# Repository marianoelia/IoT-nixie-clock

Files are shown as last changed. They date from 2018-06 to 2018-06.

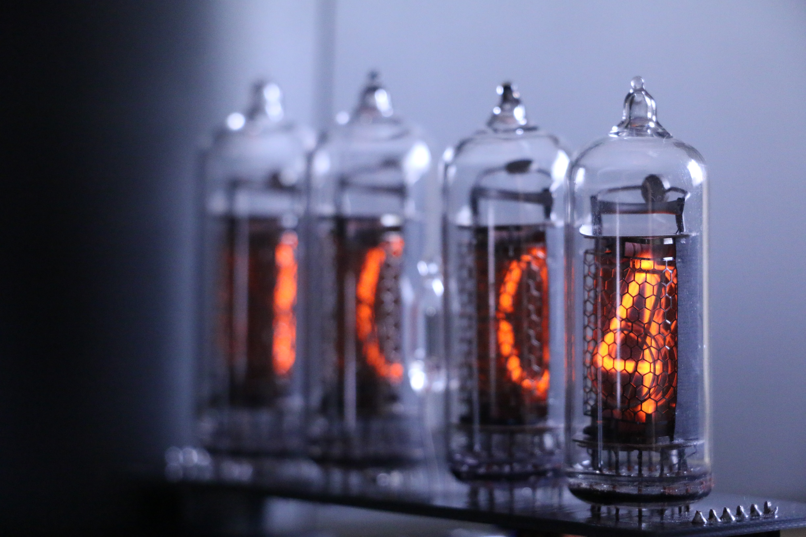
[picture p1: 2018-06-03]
Extra/Pictures/NixieClockColdLight.JPG

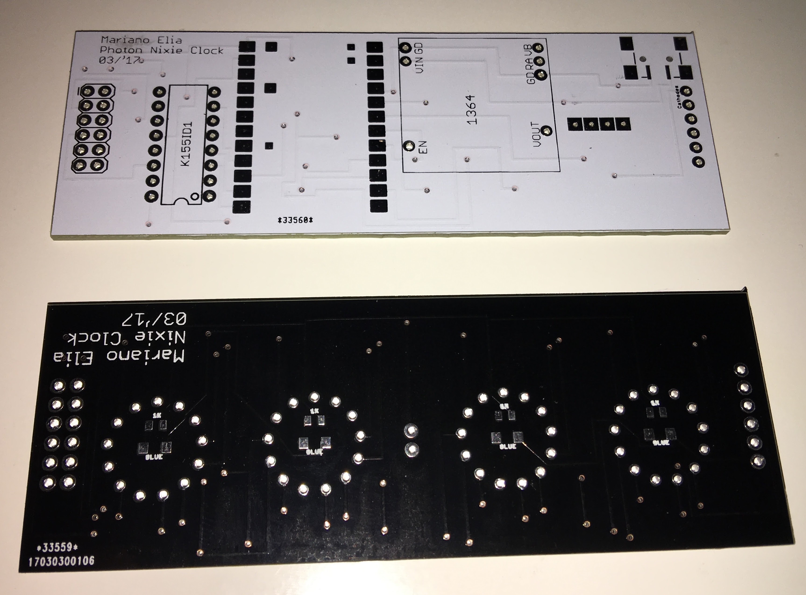
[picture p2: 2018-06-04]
Extra/Pictures/BoardsTopSide.JPG

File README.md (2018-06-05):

# Nixie Clock Project
[Link to hackster writeup tutorial](https://www.hackster.io/mrelia100/particle-photon-nixie-clock)

NixieClock

## Introduction
This is repo for my nixie clock build.

## License

This work is licensed under the  Creative Commons Attribution-ShareAlike 4.0 International License. To view a copy of this license, visit <http://creativecommons.org/licenses/by-sa/4.0/> or send a letter to Creative Commons, 444 Castro Street, Suite 900, Mountain View, California, 94041, USA.

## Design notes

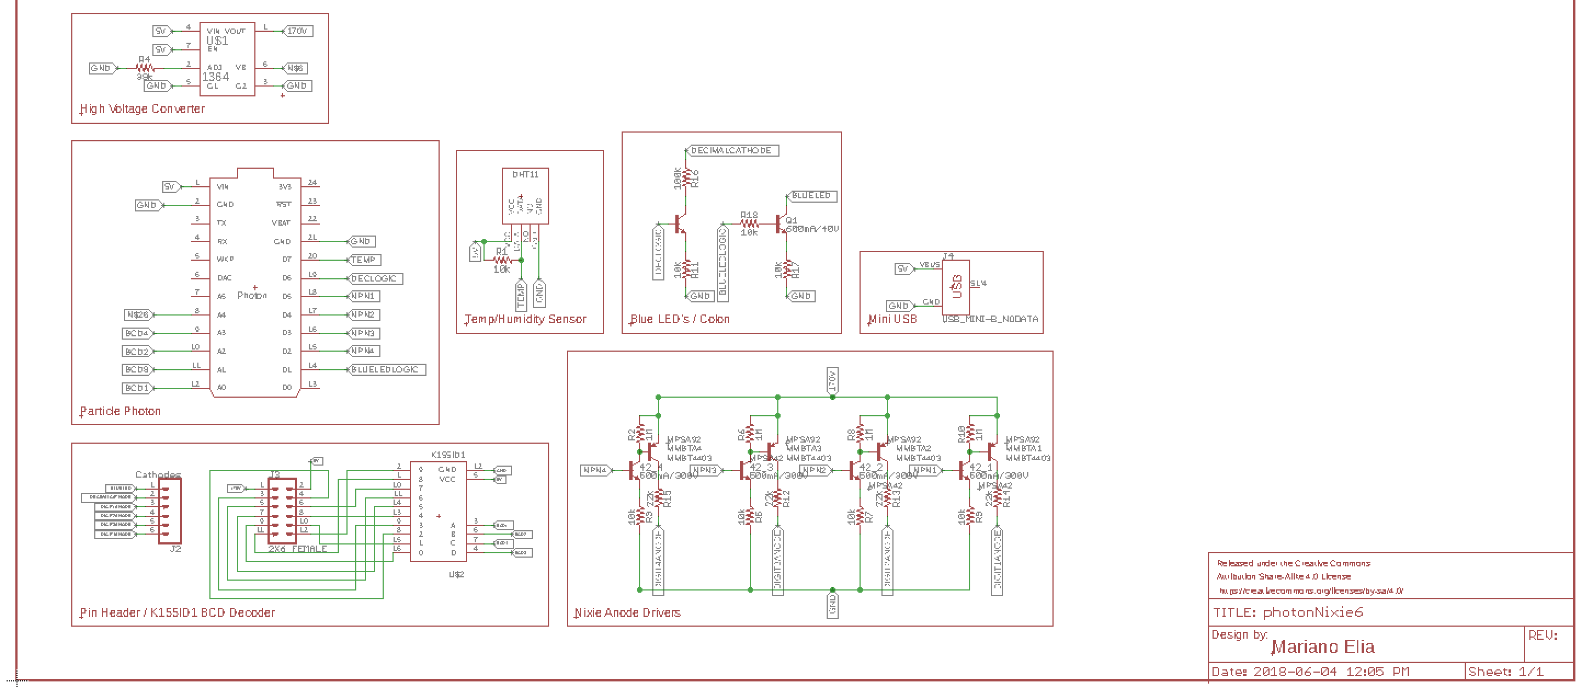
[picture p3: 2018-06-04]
BoardFiles/BottomBoard/Schematic.png

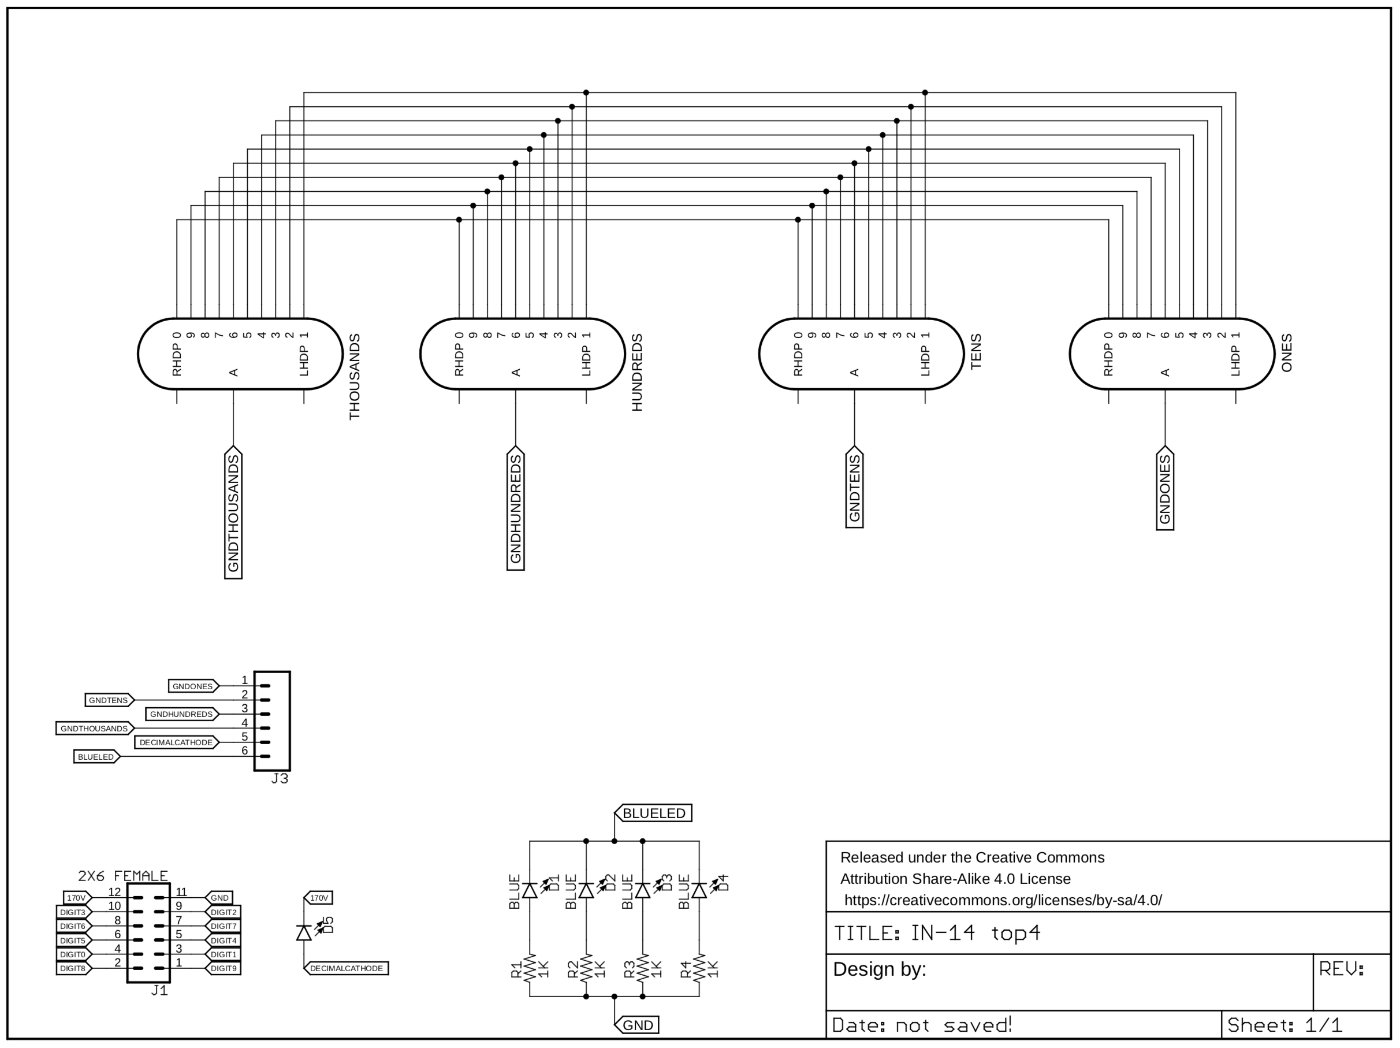
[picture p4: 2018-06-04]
BoardFiles/TopBoard/Schematic.png

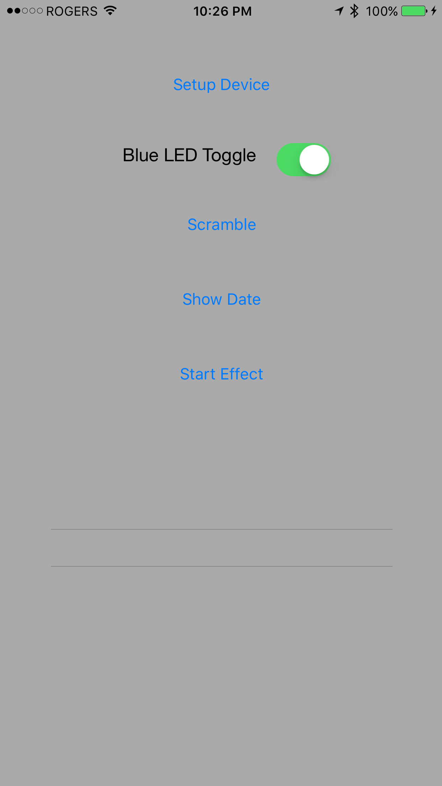
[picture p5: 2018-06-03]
Extra/Pictures/AppScreen.PNG

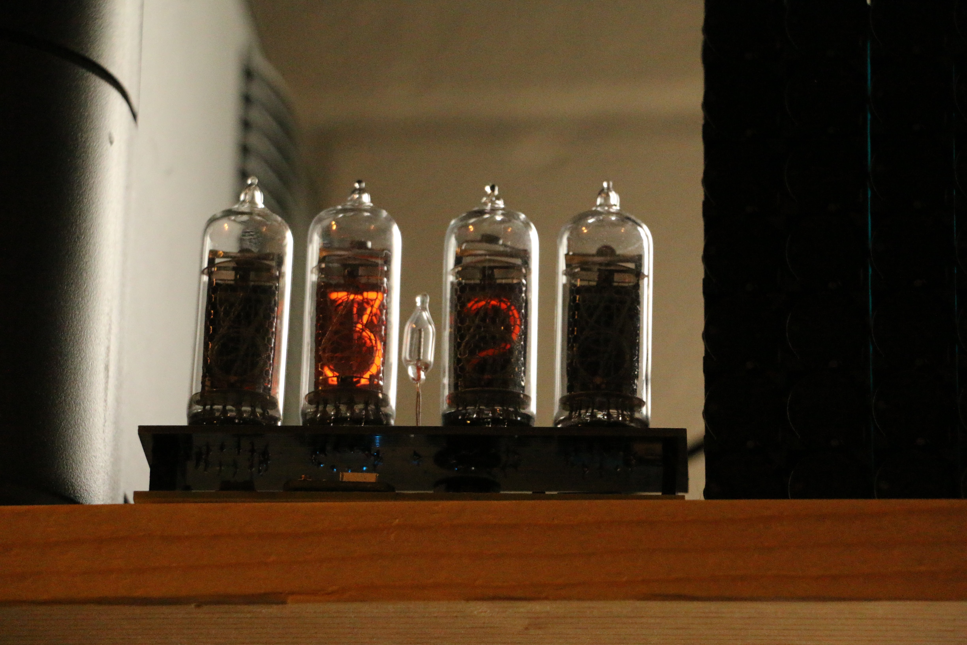
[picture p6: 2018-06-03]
Extra/Pictures/HighSpeedPhotoShowingMultiplexing.JPG

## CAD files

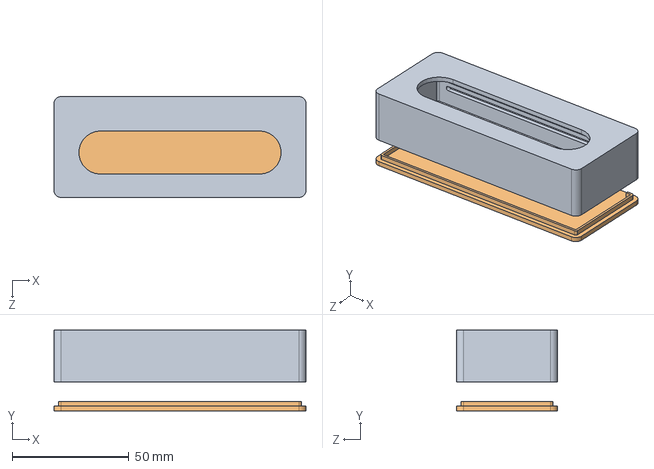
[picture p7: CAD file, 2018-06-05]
3DCase/CaseAssembly.SLDASM
108.0 x 34.6 x 43.2 mm
NixieCase1
NixieBase

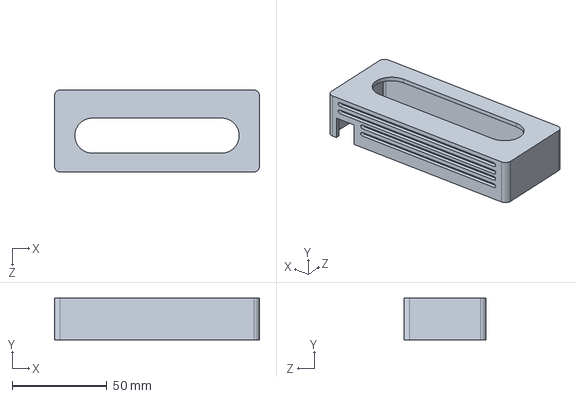
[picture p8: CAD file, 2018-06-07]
3DCase/NixieCase1.SLDPRT
108.0 x 22.0 x 43.2 mm

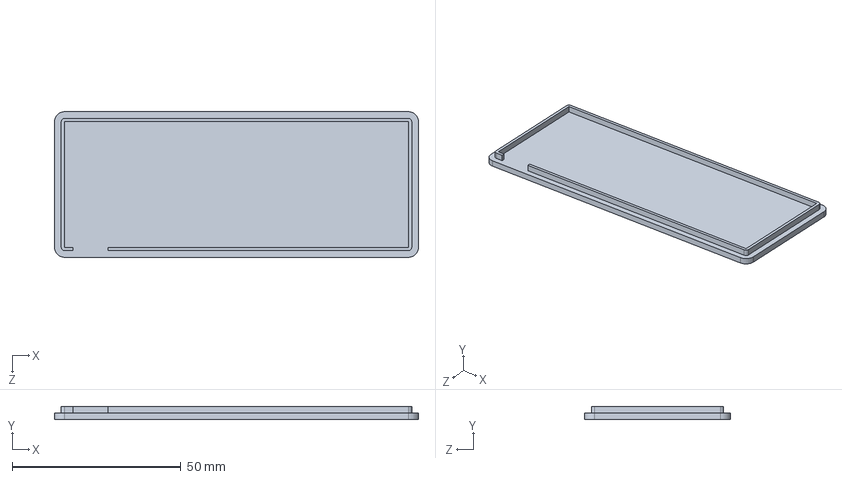
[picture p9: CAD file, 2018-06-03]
3DCase/NixieBase.SLDPRT
108.0 x 4.00 x 43.2 mm

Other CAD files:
3DCase/NixieBase.STL
3DCase/NixieCase1.SLDDRW
3DCase/NixieCase1.STL

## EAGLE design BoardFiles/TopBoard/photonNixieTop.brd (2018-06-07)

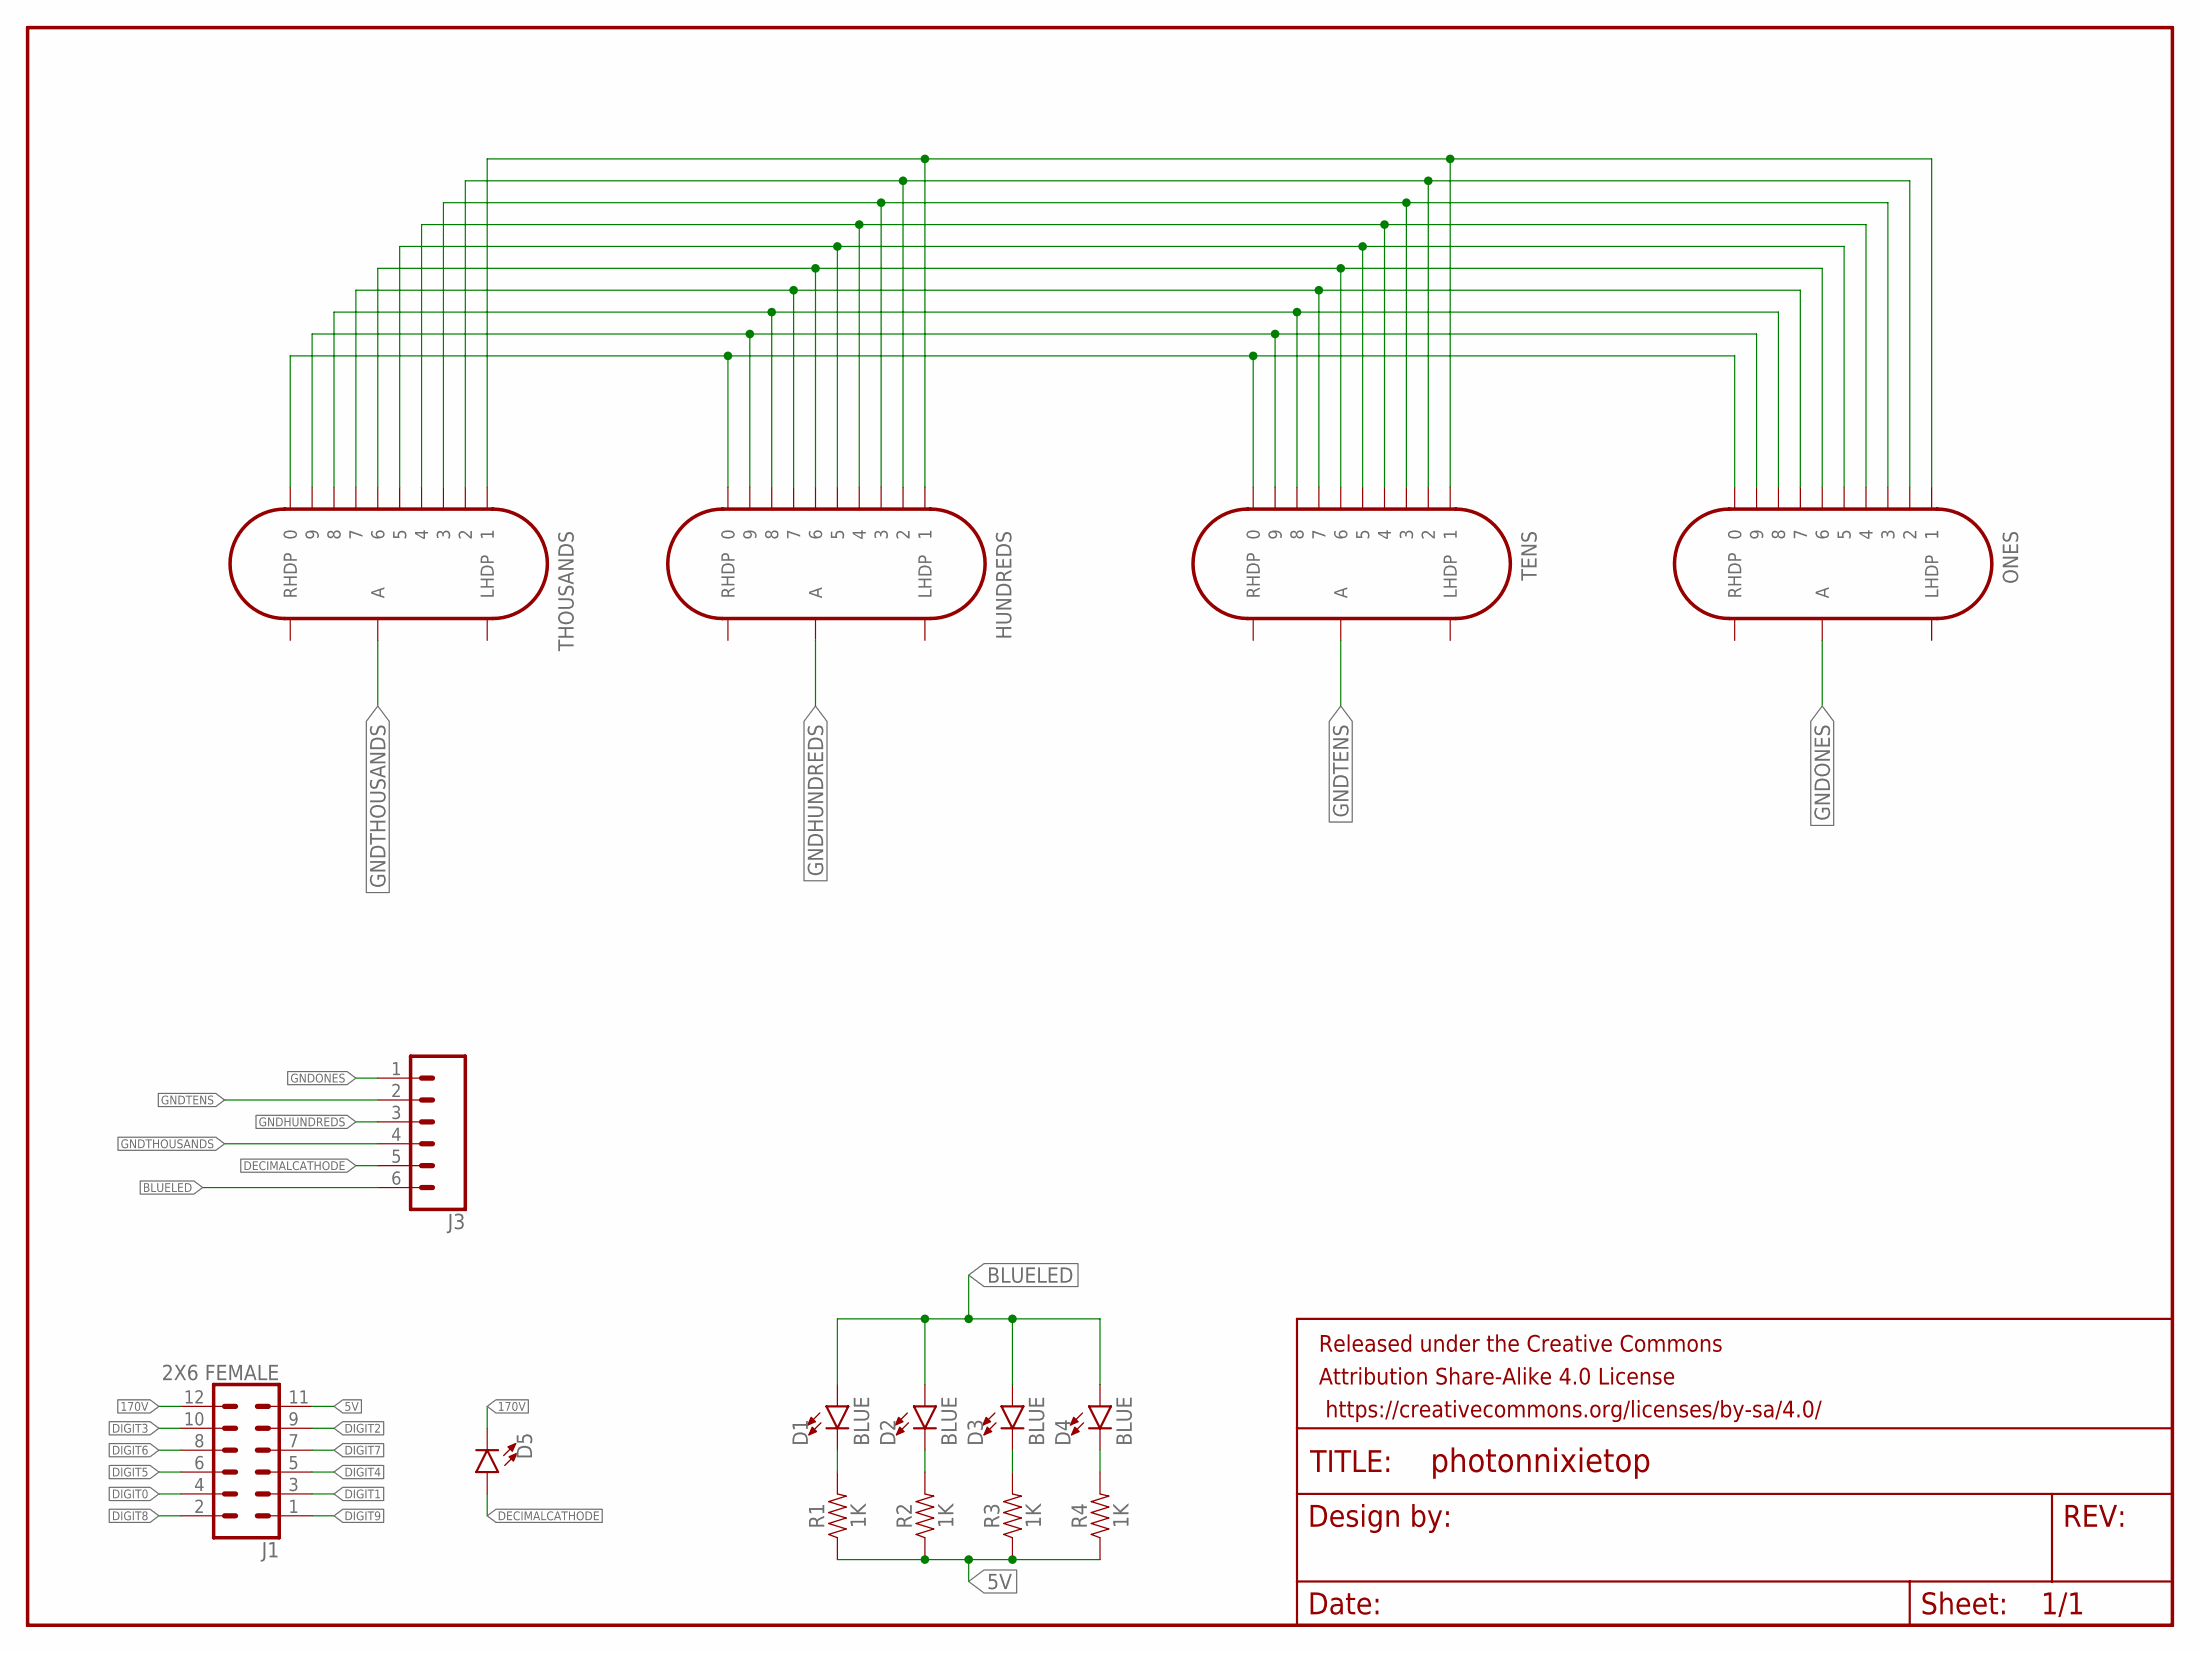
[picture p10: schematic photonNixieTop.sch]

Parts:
D1, D2, D3, D4: BLUE; LED-1206
D5: LED5MM; LED_5MM
FRAME1: FRAME-LETTER; CREATIVE_COMMONS
HUNDREDS: IN-14
J1: 2X6 FEMALE; 2X6
J3: CONN_06SILK_FEMALE_PTH; 1X06
ONES: IN-14
R1, R2, R3, R4: 1K; 0805
TENS: IN-14
THOUSANDS: IN-14

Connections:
5V: J1.11, R1.1, R2.1, R3.1, R4.1
170V: D5.K (C), J1.12
BLUELED: D1.A, D2.A, D3.A, D4.A, J3.6
DECIMALCATHODE: D5.A, J3.5
DIGIT0: HUNDREDS.0, J1.4, ONES.0, TENS.0, THOUSANDS.0
DIGIT1: HUNDREDS.1, J1.3, ONES.1, TENS.1, THOUSANDS.1
DIGIT2: HUNDREDS.2, J1.9, ONES.2, TENS.2, THOUSANDS.2
DIGIT3: HUNDREDS.3, J1.10, ONES.3, TENS.3, THOUSANDS.3
DIGIT4: HUNDREDS.4, J1.5, ONES.4, TENS.4, THOUSANDS.4
DIGIT5: HUNDREDS.5, J1.6, ONES.5, TENS.5, THOUSANDS.5
DIGIT6: HUNDREDS.6, J1.8, ONES.6, TENS.6, THOUSANDS.6
DIGIT7: HUNDREDS.7, J1.7, ONES.7, TENS.7, THOUSANDS.7
DIGIT8: HUNDREDS.8, J1.2, ONES.8, TENS.8, THOUSANDS.8
DIGIT9: HUNDREDS.9, J1.1, ONES.9, TENS.9, THOUSANDS.9
GNDHUNDREDS: HUNDREDS.A, J3.3
GNDONES: J3.1, ONES.A
GNDTENS: J3.2, TENS.A
GNDTHOUSANDS: J3.4, THOUSANDS.A
unnamed: D4.C, R4.2
unnamed: D3.C, R3.2
unnamed: D2.C, R2.2
unnamed: D1.C, R1.2

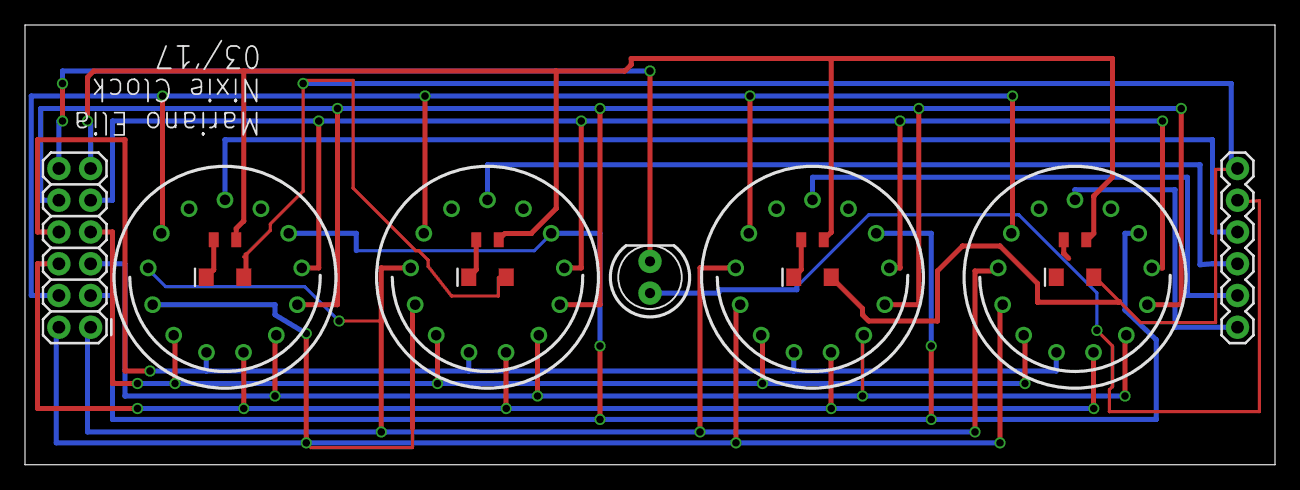
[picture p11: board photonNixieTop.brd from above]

Board: 2 copper layers, 100.0 x 35.2 mm, 16 parts (0 on the bottom side), 22 nets.

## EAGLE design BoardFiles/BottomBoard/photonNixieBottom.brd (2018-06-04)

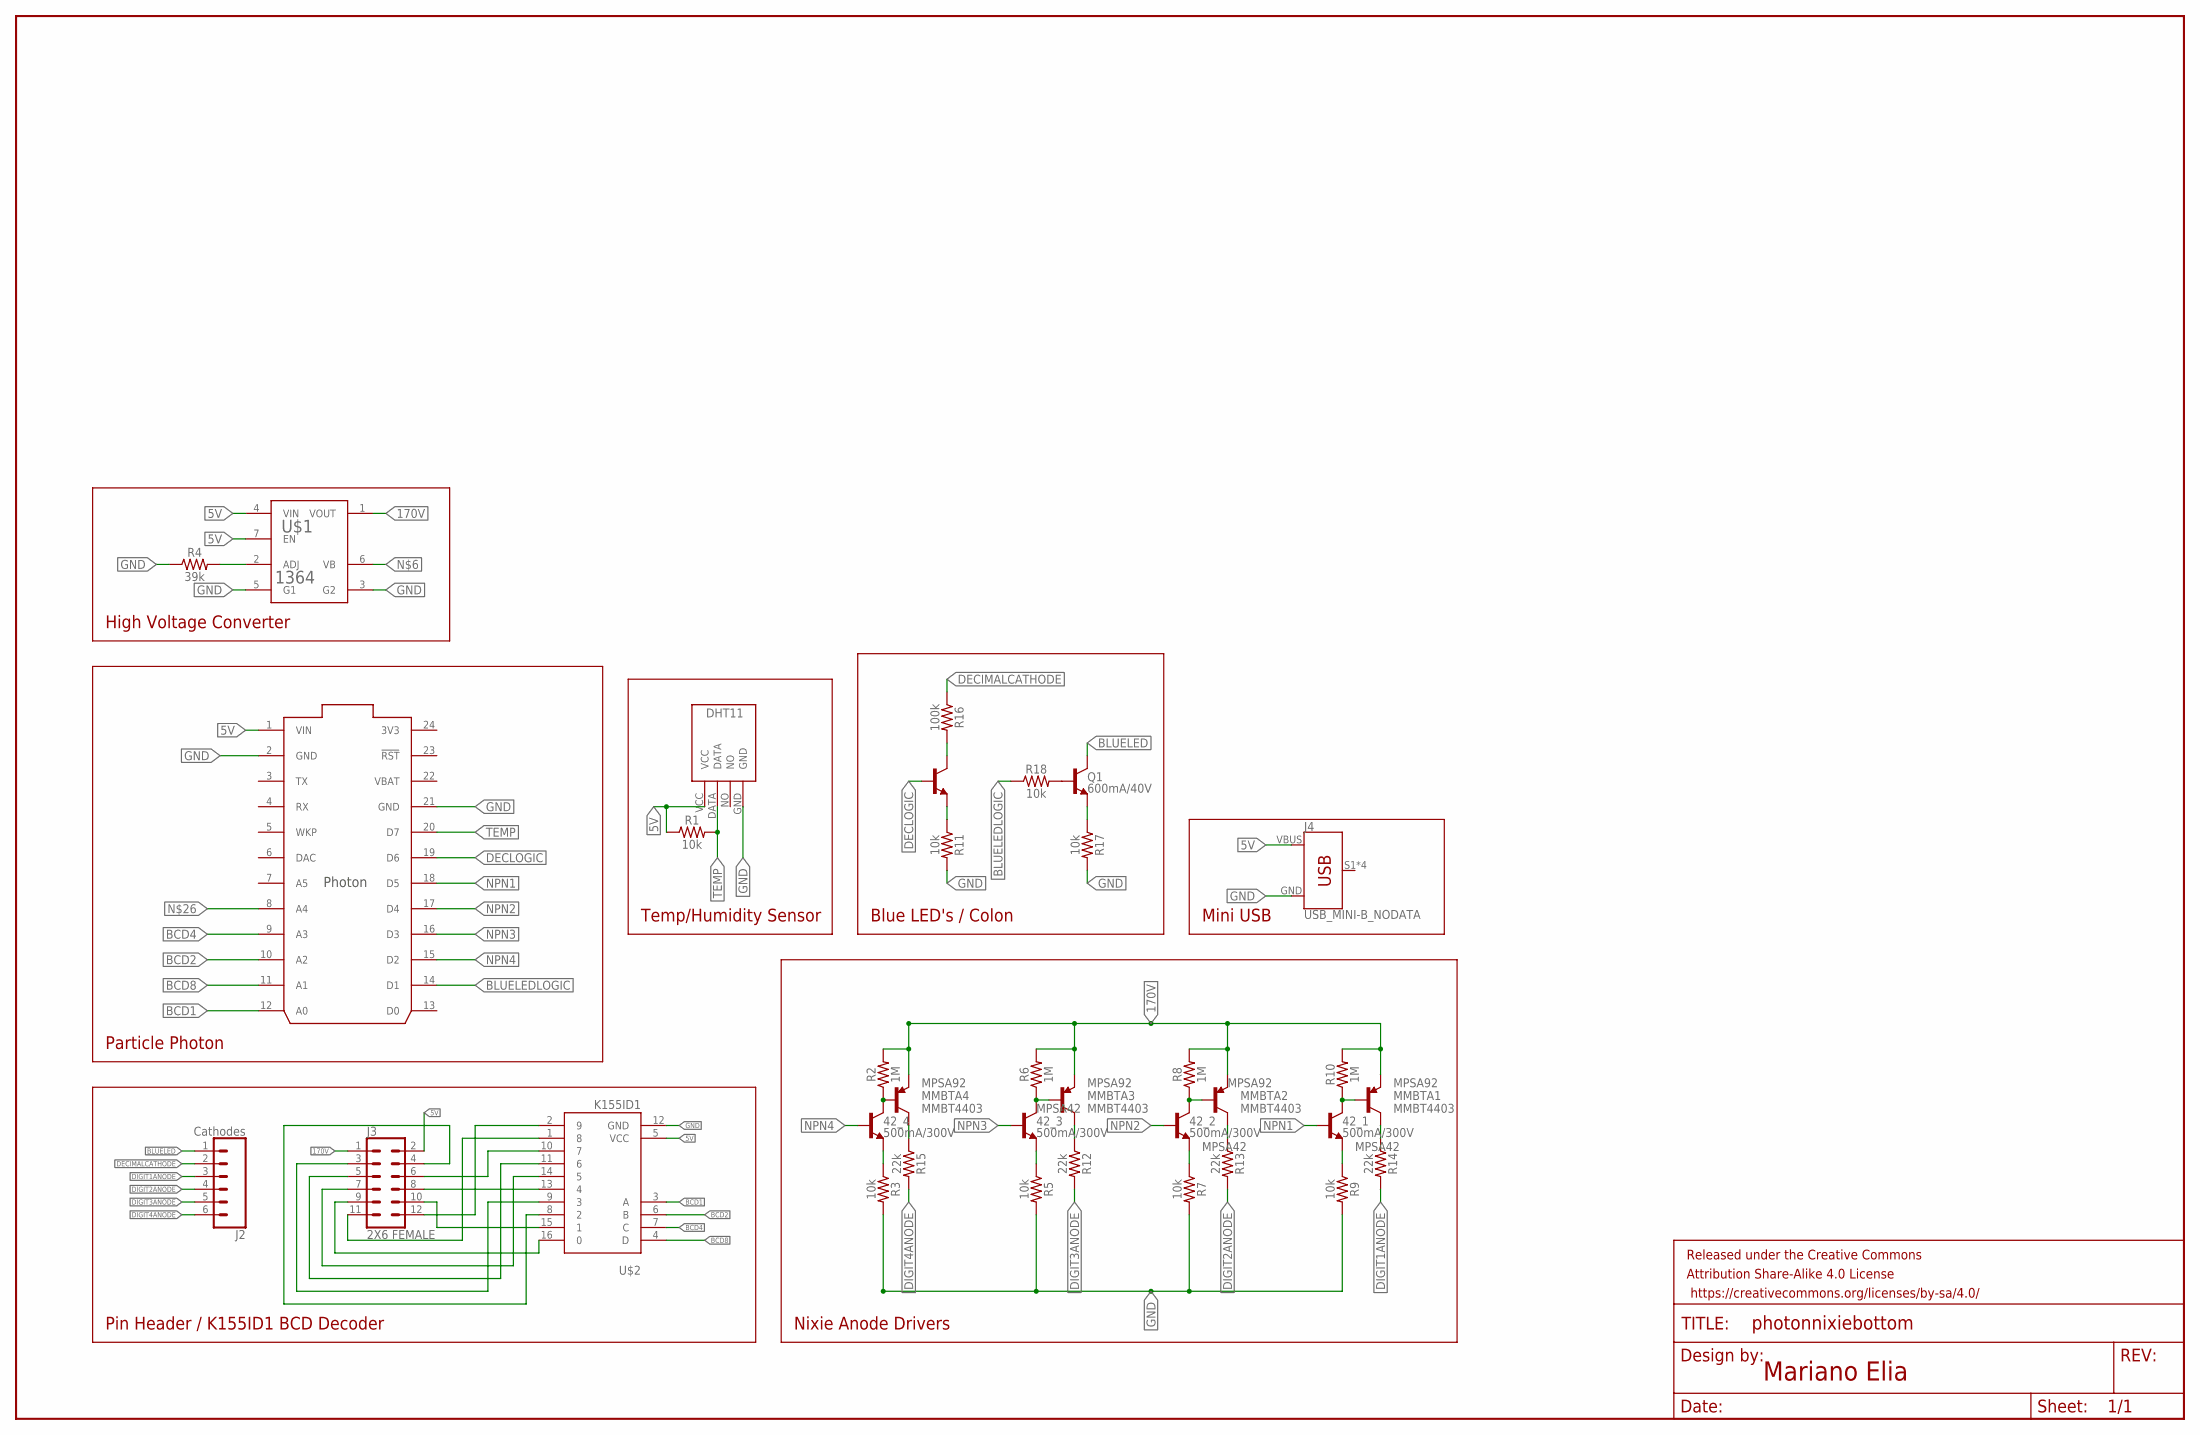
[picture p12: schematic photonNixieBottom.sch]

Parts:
42_1, 42_2, 42_3, 42_4: 500mA/300V; SOT23-3
FRAME1: FRAME-LEDGER; CREATIVE_COMMONS
J2: Cathodes; 1X06_NO_SILK
J3: 2X6 FEMALE; 2X6
J4: USB_MINI-B_NODATA; USB-MINIB_NODATA
MMBTA1, MMBTA2, MMBTA3, MMBTA4: MMBT4403; SOT23-3
MPSA7: 500mA/300V; SOT23-3
Q1: 600mA/40V; SOT23-3
R1, R3, R5, R7, R9, R11, R17, R18: 10k; 0805
R2, R6, R8, R10: 1M; 0805
R4: 39k; 0805
R12, R13, R14, R15: 22k; 0805
R16: 100k; 0805
U$1: 1364
U$2: K155ID1; DIL16-KIT
U$3: Temp/Humidity; DHT11
U$4: PHOTON_SMDNOSILK

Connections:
3V3: U$4.24 (3V3)
5V: J3.2, J4.VBUS, R1.1, U$1.4 (VIN), U$1.7 (EN), U$2.5 (VCC), U$3.VCC, U$4.1 (VIN)
170V: J3.1, MMBTA1.2 (E), MMBTA2.2 (E), MMBTA3.2 (E), MMBTA4.2 (E), R2.2, R6.2, R8.2, R10.2, U$1.1 (VOUT)
BCD1: U$2.3 (A), U$4.12 (A0)
BCD2: U$2.6 (B), U$4.10 (A2)
BCD4: U$2.7 (C), U$4.9 (A3)
BCD8: U$2.4 (D), U$4.11 (A1)
BLUELED: J2.1, Q1.3 (C)
BLUELEDLOGIC: R18.1, U$4.14 (D1)
DECIMALCATHODE: J2.2, R16.1
DECLOGIC: MPSA7.1 (B), U$4.19 (D6)
DIGIT1ANODE: J2.3, R14.2
DIGIT2ANODE: J2.4, R13.2
DIGIT3ANODE: J2.5, R12.2
DIGIT4ANODE: J2.6, R15.2
GND: J4.GND, R3.2, R4.1, R5.2, R7.2, R9.2, R11.2, R17.2, U$1.3 (G2), U$1.5 (G1), U$2.12 (GND), U$3.GND, U$4.2 (GND), U$4.21 (GND)
unnamed: J3.11, U$2.1 (8)
unnamed: J3.12, U$2.2 (9)
unnamed: R4.2, U$1.2 (ADJ)
unnamed: J3.9, U$2.16 (0)
unnamed: J3.10, U$2.15 (1)
unnamed: J3.7, U$2.14 (5)
unnamed: J3.8, U$2.13 (4)
unnamed: J3.5, U$2.11 (6)
unnamed: J3.6, U$2.10 (7)
unnamed: J3.3, U$2.9 (3)
unnamed: 42_4.2 (E), R3.1
unnamed: 42_3.2 (E), R5.1
unnamed: 42_4.3 (C), MMBTA4.1 (B), R2.1
unnamed: MPSA7.2 (E), R11.1
unnamed: 42_2.2 (E), R7.1
unnamed: 42_2.3 (C), MMBTA2.1 (B), R8.1
unnamed: J3.4, U$2.8 (2)
unnamed: 42_1.2 (E), R9.1
unnamed: 42_1.3 (C), MMBTA1.1 (B), R10.1
unnamed: 42_3.3 (C), MMBTA3.1 (B), R6.1
unnamed: MMBTA3.3 (C), R12.1
unnamed: MMBTA4.3 (C), R15.1
unnamed: MMBTA2.3 (C), R13.1
unnamed: MMBTA1.3 (C), R14.1
unnamed: MPSA7.3 (C), R16.2
unnamed: Q1.1 (B), R18.2
unnamed: Q1.2 (E), R17.1
NPN1: 42_1.1 (B), U$4.18 (D5)
NPN2: 42_2.1 (B), U$4.17 (D4)
NPN3: 42_3.1 (B), U$4.16 (D3)
NPN4: 42_4.1 (B), U$4.15 (D2)
TEMP: R1.2, U$3.DATA, U$4.20 (D7)
VBAT: U$4.22 (VBAT)

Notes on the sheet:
Particle Photon
Temp/Humidity Sensor
High Voltage Converter
Pin Header / K155ID1 BCD Decoder
Nixie Anode Drivers
Blue LED's / Colon
Mini USB
Mariano Elia

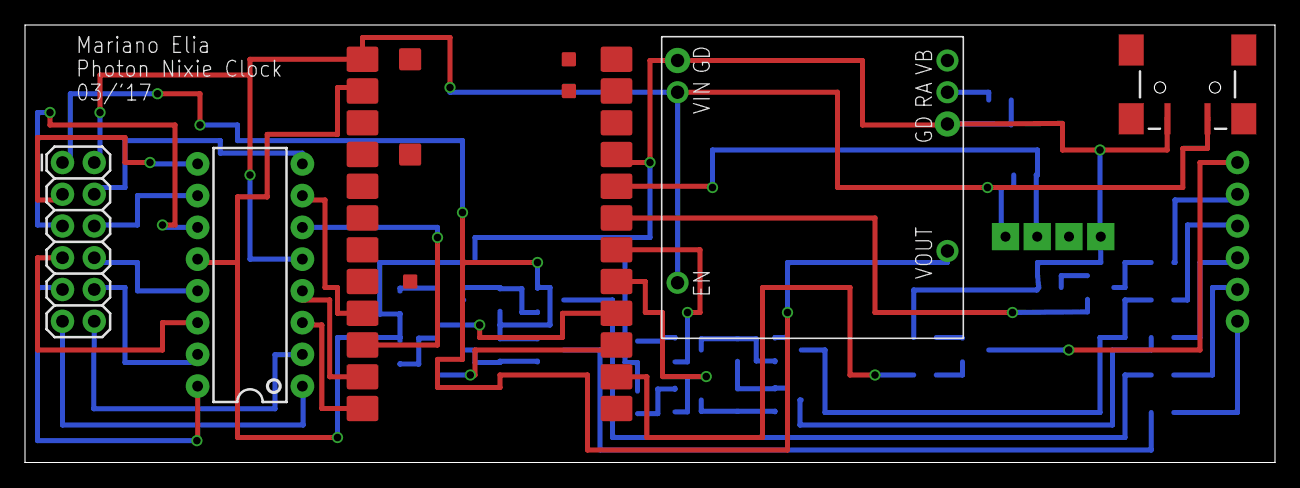
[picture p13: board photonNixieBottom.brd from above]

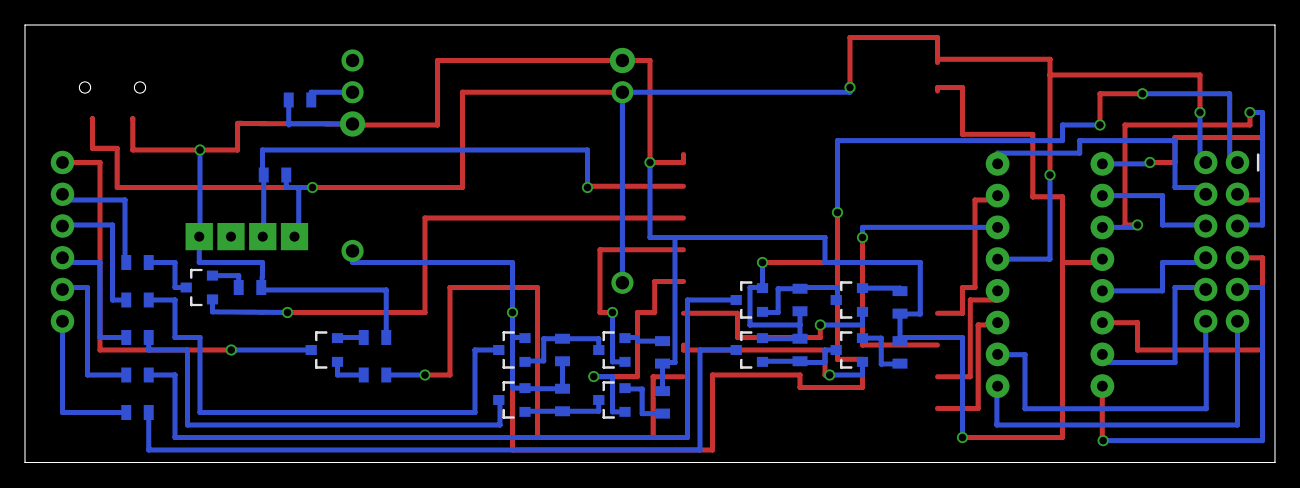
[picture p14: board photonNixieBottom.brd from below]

Board: 2 copper layers, 100.0 x 35.0 mm, 36 parts (28 on the bottom side), 47 nets.

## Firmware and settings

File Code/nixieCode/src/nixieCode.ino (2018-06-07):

/*
 * Project Particle Photon Nixie Clock
 * Description: Software to control 4 IN-14 Nixie tubes using my designed PCB's.
 * Link to repository: https://github.com/mrelia100/nixie-clock
 * Author: Mariano Elia
 * Date Published: June 5, 2018
 */

#include <Adafruit_DHT.h>

#define DHTPIN 7
#define DHTTYPE DHT11

int temperature, humidity;

DHT dht(DHTPIN, DHTTYPE);
//EEPROM Addresses
 int zoneAddress = 0;
 int lastLEDSetting = 1;

//Variable with
 int multiplexDelay = 1000;

//External Pins
 int digit1 = 5;
 int digit2 = 4;
 int digit3 = 3;
 int digit4 = 2;
 int colonPin = 6;
 int blueLEDPin = 1;

 int zone;
 int ledOnOff;
 long previousMillis = 0;

 int count = 0;
 int oldTime;
 const int segmentPins[4]={
     A1, A3, A2, A0
 };

 byte numbers[10][4] = {
  {0,0,0,1}, // 0
  {0,0,0,0}, // 1
  {1,0,0,1}, // 2
  {1,0,0,0}, // 3
  {0,1,1,1}, // 4
  {0,1,1,0}, // 5
  {0,1,0,1}, // 6
  {0,1,0,0}, // 7
  {0,0,1,1}, // 8
  {0,0,1,0}  // 9
  };

 void setup() {
    //Cloud particle funtions
     Particle.function("SetOffset", setZone);
     Particle.function("Scramble",scramble);
     Particle.function("Date", showDate);
     Particle.function("TurnLEDOn", blueLEDSwitch);
     Particle.function("Start Effect", startEffect);
     Particle.function("Get Temp", readTemperature);
     Particle.function("Get Humidity", readHumidity);
 pinMode(A0, OUTPUT);
 pinMode(A1, OUTPUT);
 pinMode(A2, OUTPUT);
 pinMode(A3, OUTPUT);

 pinMode(blueLEDPin, OUTPUT); //Pin to turn blue leds on/off
 pinMode(DHTPIN, INPUT); //Pin input from DHT11

 pinMode(digit1, OUTPUT);
 pinMode(digit2, OUTPUT);
 pinMode(digit3, OUTPUT);
 pinMode(digit4, OUTPUT);
 pinMode(colonPin, OUTPUT);

 getTimeZone();
 getLEDSettings();
 startEffect("1");
 oldTime = getTime();
 digitalWrite(colonPin, LOW);
 } ////////////// End of void setup()


 void loop(){
   unsigned long currentMillis = millis();
   showTime();
 if (currentMillis - previousMillis  > 60000){ //every 2 minutes
     previousMillis = currentMillis;
     scramble("1");
     showDate("1");
     scramble("1");
 }
 } ////////////// End of void loop()

 //used in showing digits but not called directly.
 void writeBCD(int n){
   for (int i = 0; i<4; i++){
     digitalWrite(segmentPins[i], numbers[n][i]);
   }
 }

 //Function showdigits takes a 4 digit number and displays it on the nixie tubes for a specific length of time.
 void showdigits(int number, int delayLength){ //number will be up to 4 long
 /* To show the multiplexing effect, anodes of the Nixie Tubes will be cycled
 */
 delayLength = delayLength/4;
 for (int current = 0; current<delayLength; current++){
  int thousands = number/1000;
  digitalWrite(digit4,LOW);
  writeBCD(thousands);
  if ( thousands == 20){ //0
     digitalWrite(digit1, LOW);
 }
 else{
   digitalWrite(digit1, HIGH);
   }
   digitalWrite(digit2, LOW);
   digitalWrite(digit3, LOW);
   delayMicroseconds(multiplexDelay);

 int hundreds = number%1000/100;
   digitalWrite(digit1, LOW);
   writeBCD(hundreds); //234/100 is 2.
   digitalWrite(digit2, HIGH);
   digitalWrite(digit3, LOW);
   digitalWrite(digit4, LOW);
   delayMicroseconds(multiplexDelay);

 int tens = ((number%1000)%100)/10;
   digitalWrite(digit1, LOW);
   digitalWrite(digit2, LOW);
   writeBCD(tens);
   digitalWrite(digit3, HIGH);
   digitalWrite(digit4, LOW);
   delayMicroseconds(multiplexDelay);

 int ones = ((number%1000)%100)%10;
   digitalWrite(digit1, LOW);
   digitalWrite(digit2, LOW);
   digitalWrite(digit3, LOW);
   writeBCD(ones);
   digitalWrite(digit4, HIGH);
   delayMicroseconds(multiplexDelay);
   digitalWrite(digit4, LOW);
 }
 }

 int scramble(String command){
 for (int i = 0; i<2; i++){
 for (int j = 0; j<=9999; j+=1111){
 showdigits(j, 30); //8
 }
 }
 return 1;
 }


 int showTime(){
 int hourPlusMinute = getTime();
 showdigits(hourPlusMinute,8);
 return hourPlusMinute;
 }


 int showDate(String command){
 int date = Time.month()*100+Time.day();
 showdigits(date, 3000);
     return 1;
 }


 //////////////////////////////////////////////// Time Functions ///////////////////////////

 void getTimeZone(){
     EEPROM.get(zoneAddress, zone);
     Time.zone(zone);
 }

 int blueLEDSwitch(String command){
     if (command == "1"){
      ledOnOff = 1;
     digitalWrite(blueLEDPin, ledOnOff);
     digitalWrite(colonPin, HIGH); //neon bulb
     EEPROM.put(lastLEDSetting, ledOnOff);
     return 1;
     }
     else {
         ledOnOff = 0;
     digitalWrite(blueLEDPin, ledOnOff);
     digitalWrite(colonPin, LOW); //neon bulb
     EEPROM.put(lastLEDSetting, ledOnOff);
     return 1;
     }
     return 0;
 }

 void getLEDSettings(){
     EEPROM.get(lastLEDSetting, ledOnOff);
     if (ledOnOff == 1) {
     digitalWrite(blueLEDPin, HIGH);
   }
     else {
     digitalWrite(blueLEDPin, LOW);
 }
 }


 int getTime(){
    Time.zone(zone);
     int hourPlusMinute = (Time.hourFormat12())*100+Time.minute();
 return hourPlusMinute;
 }

 int setZone(String command){
     zone = command.toInt();
     EEPROM.put(zoneAddress, zone);
 return 1;
 }

 /*
 * Start effect starts at 00:00 and cycles the minutes digit a couple times before
 * landing on the correct digit. It then proceeds to the tens digit and cycles it.
 */
 int startEffect(String command){
    int fullTime = getTime(); //Receive function in full form, eg 1230
    int ones = ((fullTime%1000)%100)%10;
    int tens = ((fullTime%1000)%100)/10;
    int hundreds = fullTime%1000/100;
     showdigits(0000,1000);

     for (int i = 0; i<4; i++){
         if (i ==0){
     for (int j = 0; j<9; j++){
         String string = "000";
         String numToString = String(j);
         string.concat(numToString);
         int number = string.toInt();
         showdigits(number, 30);
     }
         }

     if (i == 1){
         for (int j = 0; j<9; j++){
         String string = "00";
         String numToString = String(j);
         string.concat(numToString);
         string.concat(ones);
         int number = string.toInt();
         showdigits(number, 30);
     }
     }

         if (i == 2){
         for (int j = 0; j<9; j++){
         String string = "0";
         String numToString = String(j);
         string.concat(numToString);
         string.concat(tens);
         string.concat(ones);
         int number = string.toInt();
         showdigits(number, 30);
     }
     }
         if (i == 3){
         for (int j = 0; j<9; j++){
         String string = "";
         String numToString = String(j);
         string.concat(numToString);
         string.concat(hundreds);
         string.concat(tens);
         string.concat(ones);
         int final = string.toInt();
         showdigits(final, 30);
     }
     }

  }
    showdigits(fullTime, 4000);
   return 1;
 }

int readTemperature(String command){
temperature = dht.getTempCelcius();
delay(10);
return temperature;
 }

 int readHumidity(String command){
humidity = dht.getHumidity();
delay(10);
return humidity;
 }

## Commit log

2018-06-03 Added solidworks files
    [CaseAssembly.SLDASM, NixieBase.SLDPRT, NixieCase1.SLDPRT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]
2018-06-03 Added stl of base
    [NixieBase.SLDPRT, NixieBase.STL]
2018-06-04 Added Datasheets
    [CaseAssembly.SLDASM, NixieCase1.SLDPRT, NixieCase1.STL]
2018-06-04 Added eagle boards
    [photonNixie.brd, photonNixie.sch]
2018-06-04 Added top board
    [photonNixieBottom.brd, photonNixieBottom.sch, photonNixieTop.brd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]
2018-06-05 Changed 3D case and updated code
    [CaseAssembly.SLDASM]
2018-06-07 Code and case changes
    [NixieCase1.SLDPRT, NixieCase1.STL, photonNixieTop.brd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]

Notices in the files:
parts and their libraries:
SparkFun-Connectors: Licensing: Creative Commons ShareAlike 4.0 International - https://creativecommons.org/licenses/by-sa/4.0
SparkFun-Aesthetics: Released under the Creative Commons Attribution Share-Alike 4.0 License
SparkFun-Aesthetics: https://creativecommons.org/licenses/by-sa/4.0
